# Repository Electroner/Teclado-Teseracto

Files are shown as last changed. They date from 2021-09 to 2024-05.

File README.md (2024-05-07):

# Teclado Personalizado en Español + PCB  

En este repositorio encontraras desde los datasheet de cada parte que he usado hasta los archivos originales del autocad, con todos los archivos descargados deberias ser capaz de poder crear y manufacturar este teclado sin ningun problema.

Este teclado usa un Atmega32u4 como controllador y un decodificador/Demultiplexor CD74HC154 4-a-16, Suficiente para conseguir un tiempo de respuesta igual o superior a los mejores teclados comerciales actuales (1060Hz).Pruebas realizadas con el codigo actual. Ademas se ha decido "prescindir" de un teclado numerico real, y lo que se ha hecho es conectar los numeros del numpad a  los numeros de la parte superior del teclado, por lo que las teclas tanto del numpad como los de la parte superior son los mismas, al igual con el intro y "." (Ver Esquematica).

Para el cuerpo y Plate se ha optado por una fabricacion completa de metacrilato atornillada de extremo a extremo con 28 tornillos que provocaran una sujeccion y una robustez sin igual. El diseño en todo momento de cada parte se ha realizado pensando en su mantenimiento y facilidad de reparacion.

Se ha actualizado a la version N-keyRollOver con unas modificaciones en las librerias de Keyboard.h y Keyboard.cpp

## Imagenes

Teclado Finalizado (No leds):

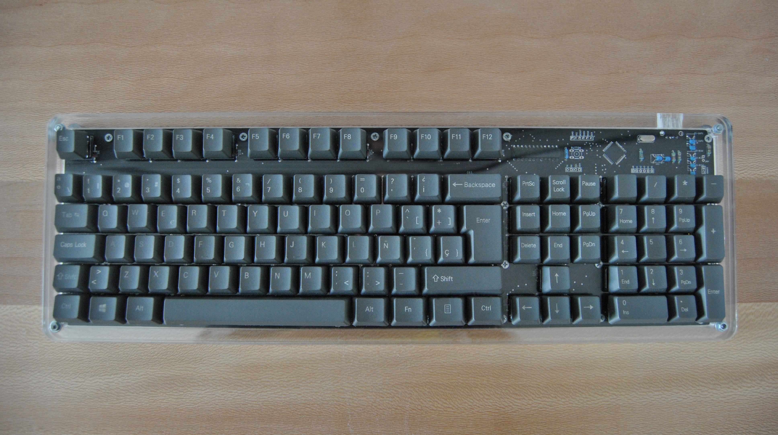
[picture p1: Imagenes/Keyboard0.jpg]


TECLADO

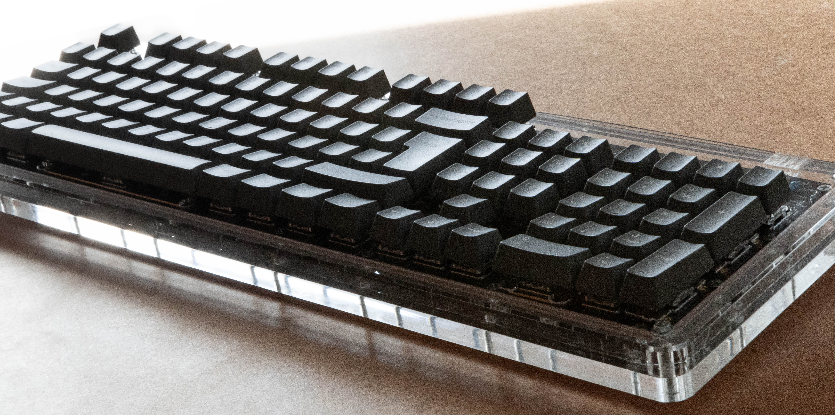
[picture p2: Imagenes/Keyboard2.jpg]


TECLADO

TECLADO

Teclado Finalizado (Leds):

TECLADO

Componentes de la PCB:

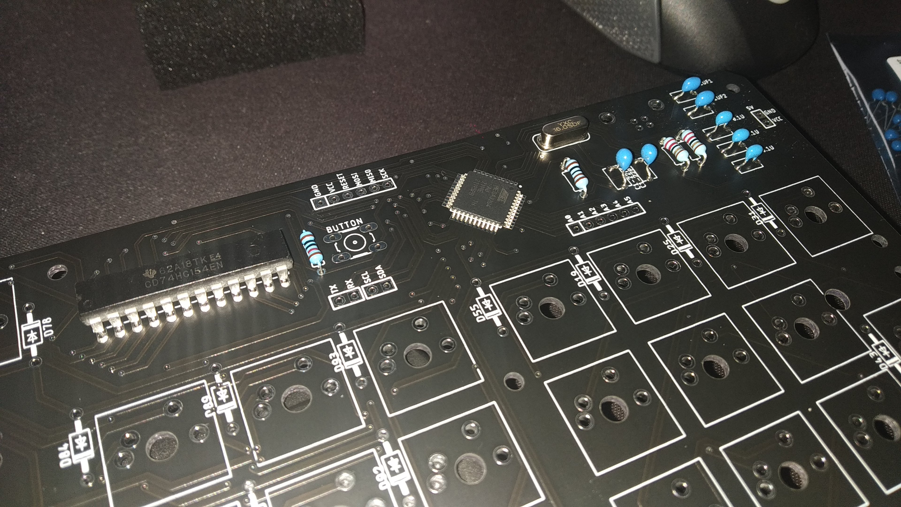
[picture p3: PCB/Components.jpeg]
PCB


Vista Previa de la PCB:

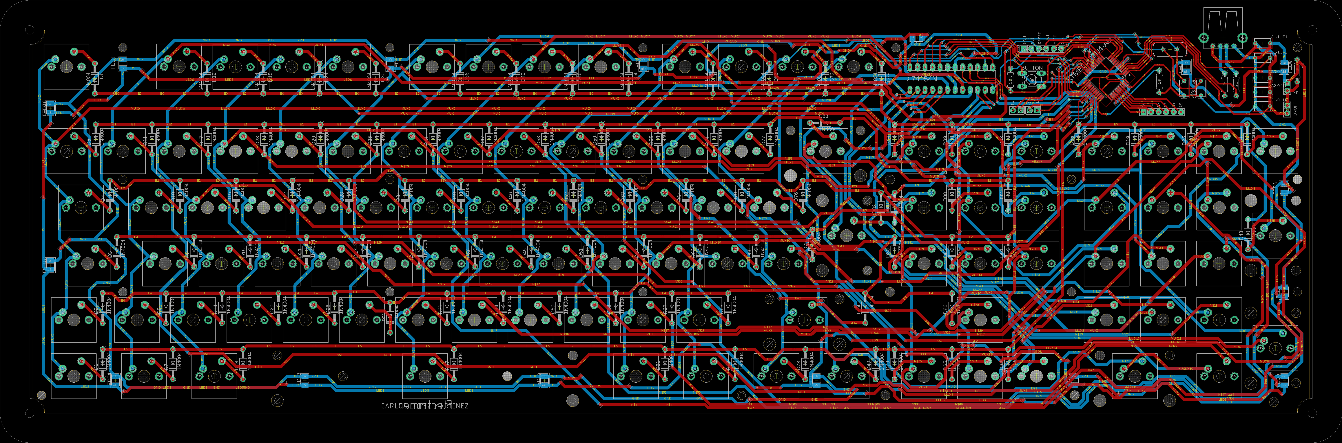
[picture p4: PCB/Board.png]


Schematic:

PLANO

Plano Plancha Superior (Plate):

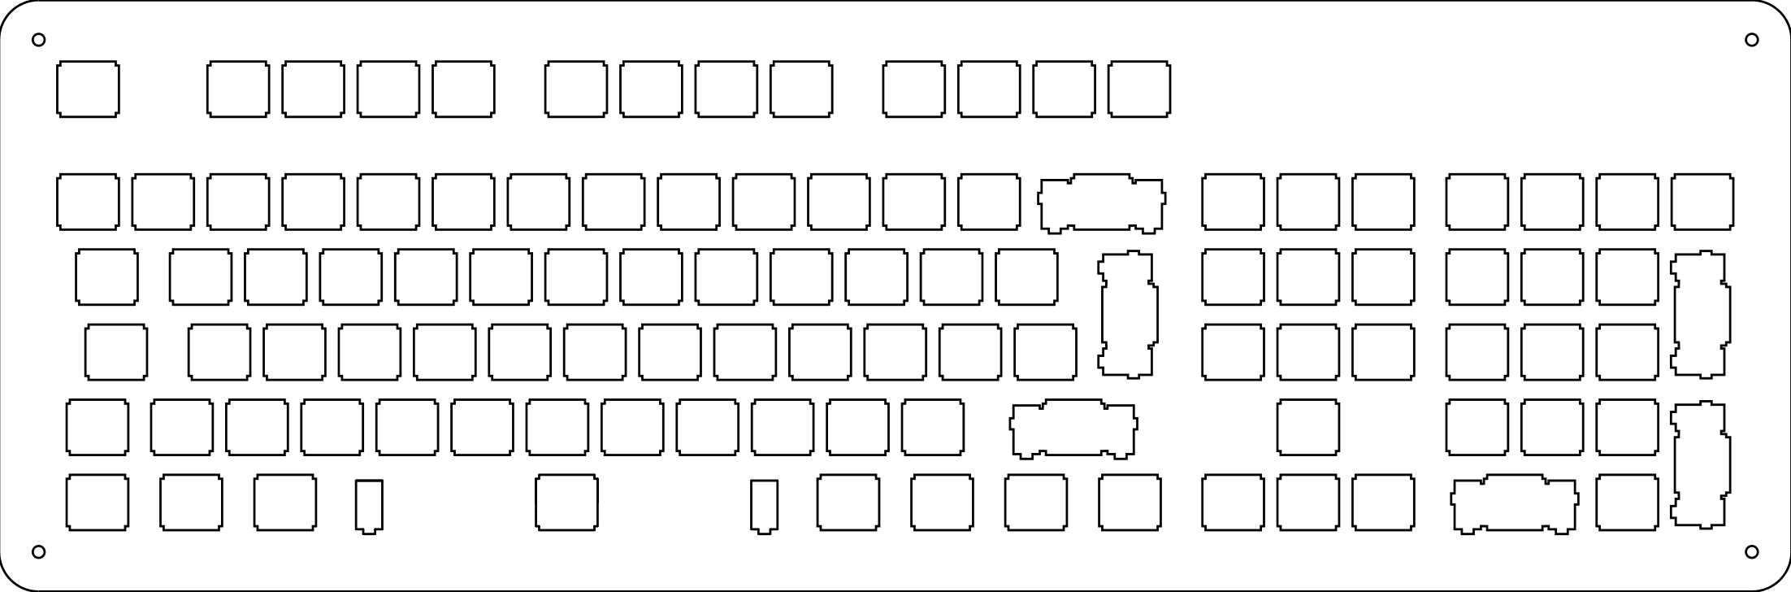
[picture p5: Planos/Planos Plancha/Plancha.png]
PLANO


## Recursos Usados

-   [Alguna Investigacion y aprendizaje](https://github.com/w4ilun/pocket-keyboard)

Y varias paginas para datos concretos como funciones en eagle,ayuda con el bootloader y ejemplos de otros teclados.

-   [Ayuda con el bootloader](https://forum.arduino.cc/t/burning-bootloader-to-custom-board-atmega32u4/890015)
-   [Ayuda con el N-key](https://forum.arduino.cc/t/how-to-program-n-key-rollover-atmega32u4/938418)

## Software Usado

-   [Editor de Layaout Teclado](http://www.keyboard-layout-editor.com/)
-   [Autocad](https://www.autodesk.es/products/autocad/overview?term=1-YEAR&tab=subscription)
-   [FreeCad](https://www.freecadweb.org/)
-   [Eagle](https://www.autodesk.com/products/eagle/free-download)
-   [Componentes Eagle](https://componentsearchengine.com/)
-   [Produccion de la PCB](https://jlcpcb.com/)
-   [Compra de los componentes](https://lcsc.com/)
-   [Corte de metacrilato (Tienda Local)](https://ecoplasticlaser.com/)

## Instalacion y Compilacion

Recomiendo el Arduino 1.8 (Legacy IDE (1.8.X)) en su version portable. 
Para poder compilar la placa y añadir los archivos personalizados vamos a seguir estos pasos:

1. En ./hardware/ meteremos la carpeta CLMKeyboard donde estan los archivos personalizados.
2. Dentro de las librerias (./libraries/Keyboard) vamos a sustituir los archivos keyboard.c y Keyboard.h
3. Dentro de arduino deberia aparacer nuestra Placa como CLM Keyboard.
4. Compilamos y subimos.

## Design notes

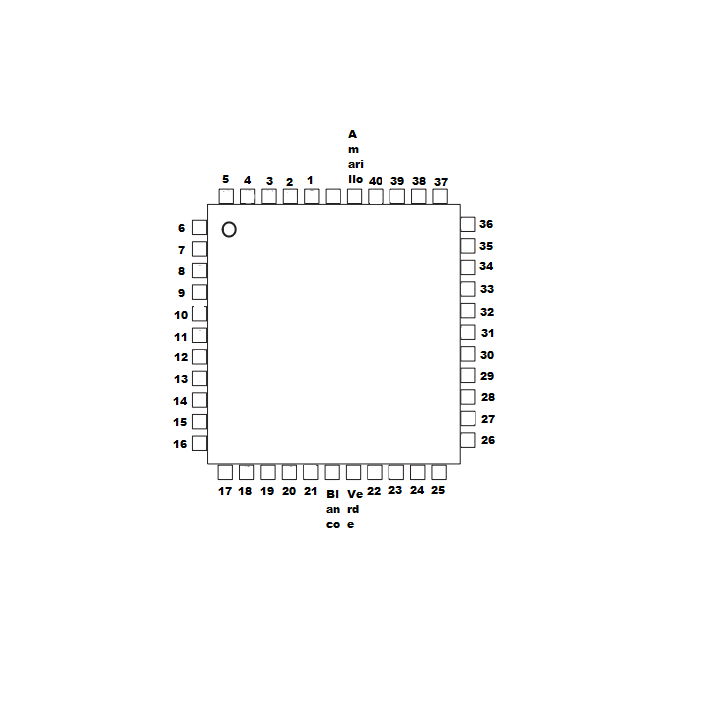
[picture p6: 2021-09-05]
Componentes/Pinout Programador.png

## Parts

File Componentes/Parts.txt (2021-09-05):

https://www.lcsc.com/product-detail/Switching-Diode_ST-Semtech-1N4148_C14516.html
https://www.lcsc.com/product-detail/Multilayer-Ceramic-Capacitors-MLCC-Leaded_Dersonic-CD1H220JC9BECHD000_C263190.html
https://www.lcsc.com/product-detail/Crystals_Yangxing-Tech-X49SD16MSD2SC_C16212.html
https://www.lcsc.com/product-detail/Multilayer-Ceramic-Capacitors-MLCC-Leaded_Dersonic-CD1H105MC9BEF4E000_C263189.html
https://www.lcsc.com/product-detail/Multilayer-Ceramic-Capacitors-MLCC-Leaded_Murata-Electronics-RDER71H104K0K1H03B_C162685.html
https://www.lcsc.com/product-detail/Through-Hole-Resistors_UNI-ROYAL-Uniroyal-Elec-MFR0W4F220JA50_C58611.html
https://www.lcsc.com/product-detail/Through-Hole-Resistors_UNI-ROYAL-Uniroyal-Elec-MFR0W4F1001A50_C57435.html
https://www.lcsc.com/product-detail/ATMEL-AVR_Microchip-Tech-ATMEGA32U4-AU_C44854.html
https://es.aliexpress.com/item/1005002657470319.html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

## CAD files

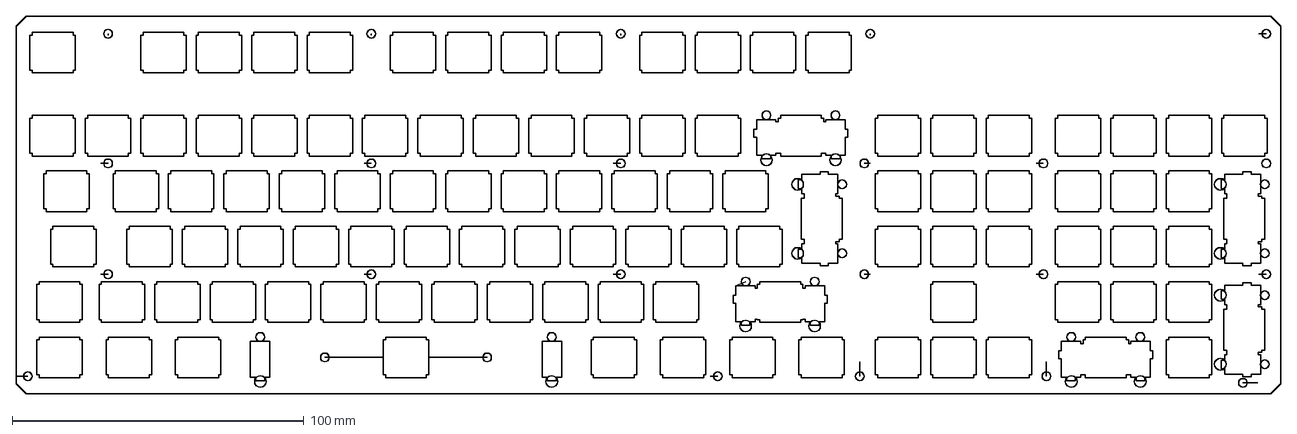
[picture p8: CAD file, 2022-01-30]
Planos/Plano PCB/PCB.dxf
433.5 x 129.5 mm

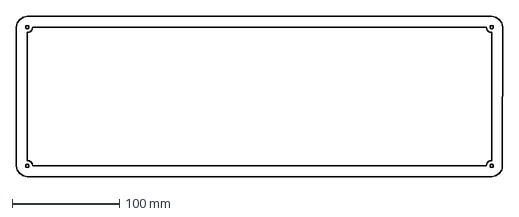
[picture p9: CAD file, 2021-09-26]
Planos/Planos Carcasa/Borde.dxf
453.5 x 149.5 mm

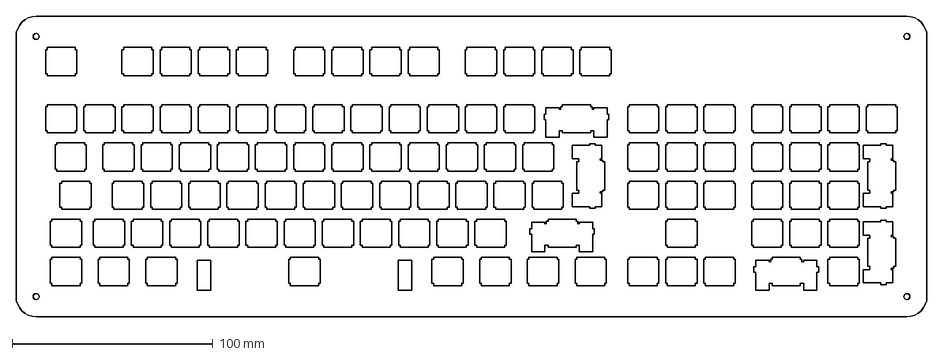
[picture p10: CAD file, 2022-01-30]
Planos/Planos Plancha/Plate.dxf
453.5 x 149.5 mm

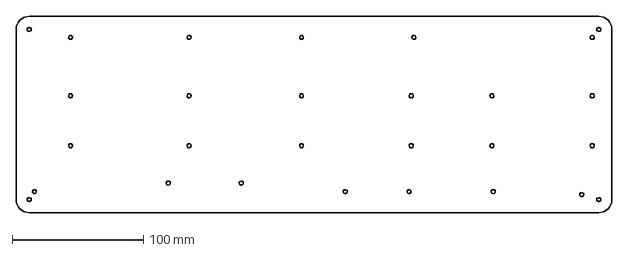
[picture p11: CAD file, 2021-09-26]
Planos/Planos Carcasa/Plancha Inferior.dxf
453.5 x 149.5 mm

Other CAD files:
Planos/Plano PCB/PCB.dwg
Planos/Planos Carcasa/Borde.dwg
Planos/Planos Carcasa/Plancha Inferior.dwg
Planos/Planos Plancha/Plate.dwg

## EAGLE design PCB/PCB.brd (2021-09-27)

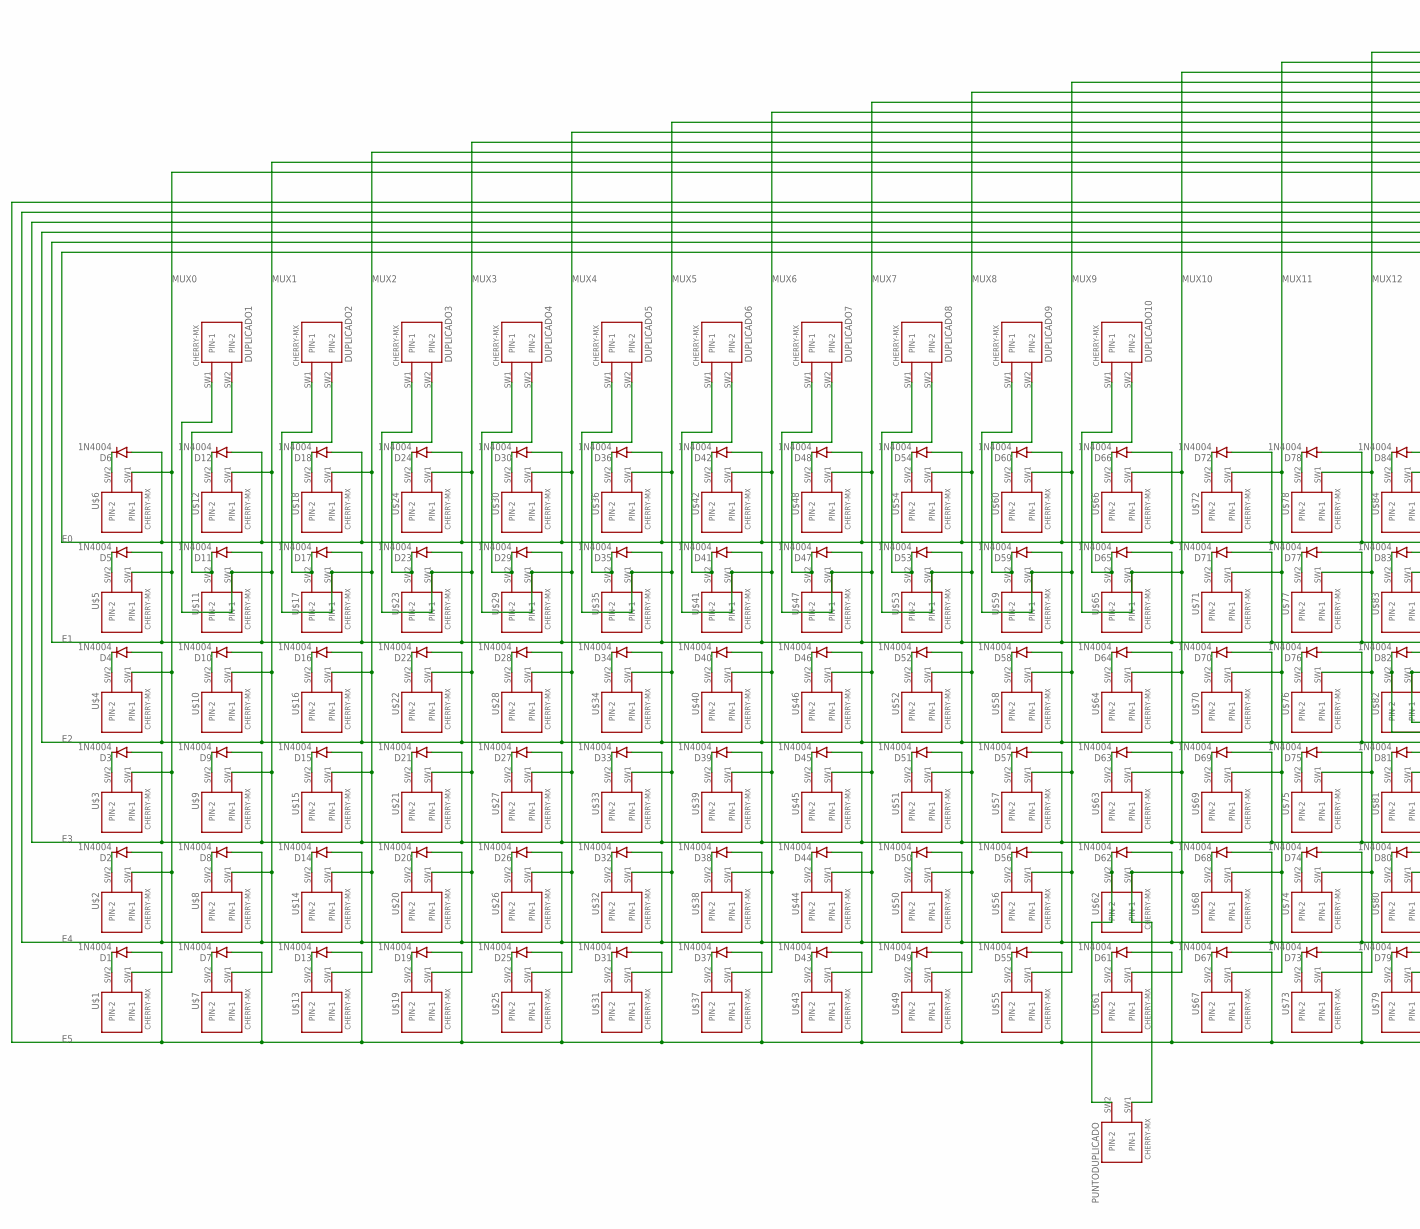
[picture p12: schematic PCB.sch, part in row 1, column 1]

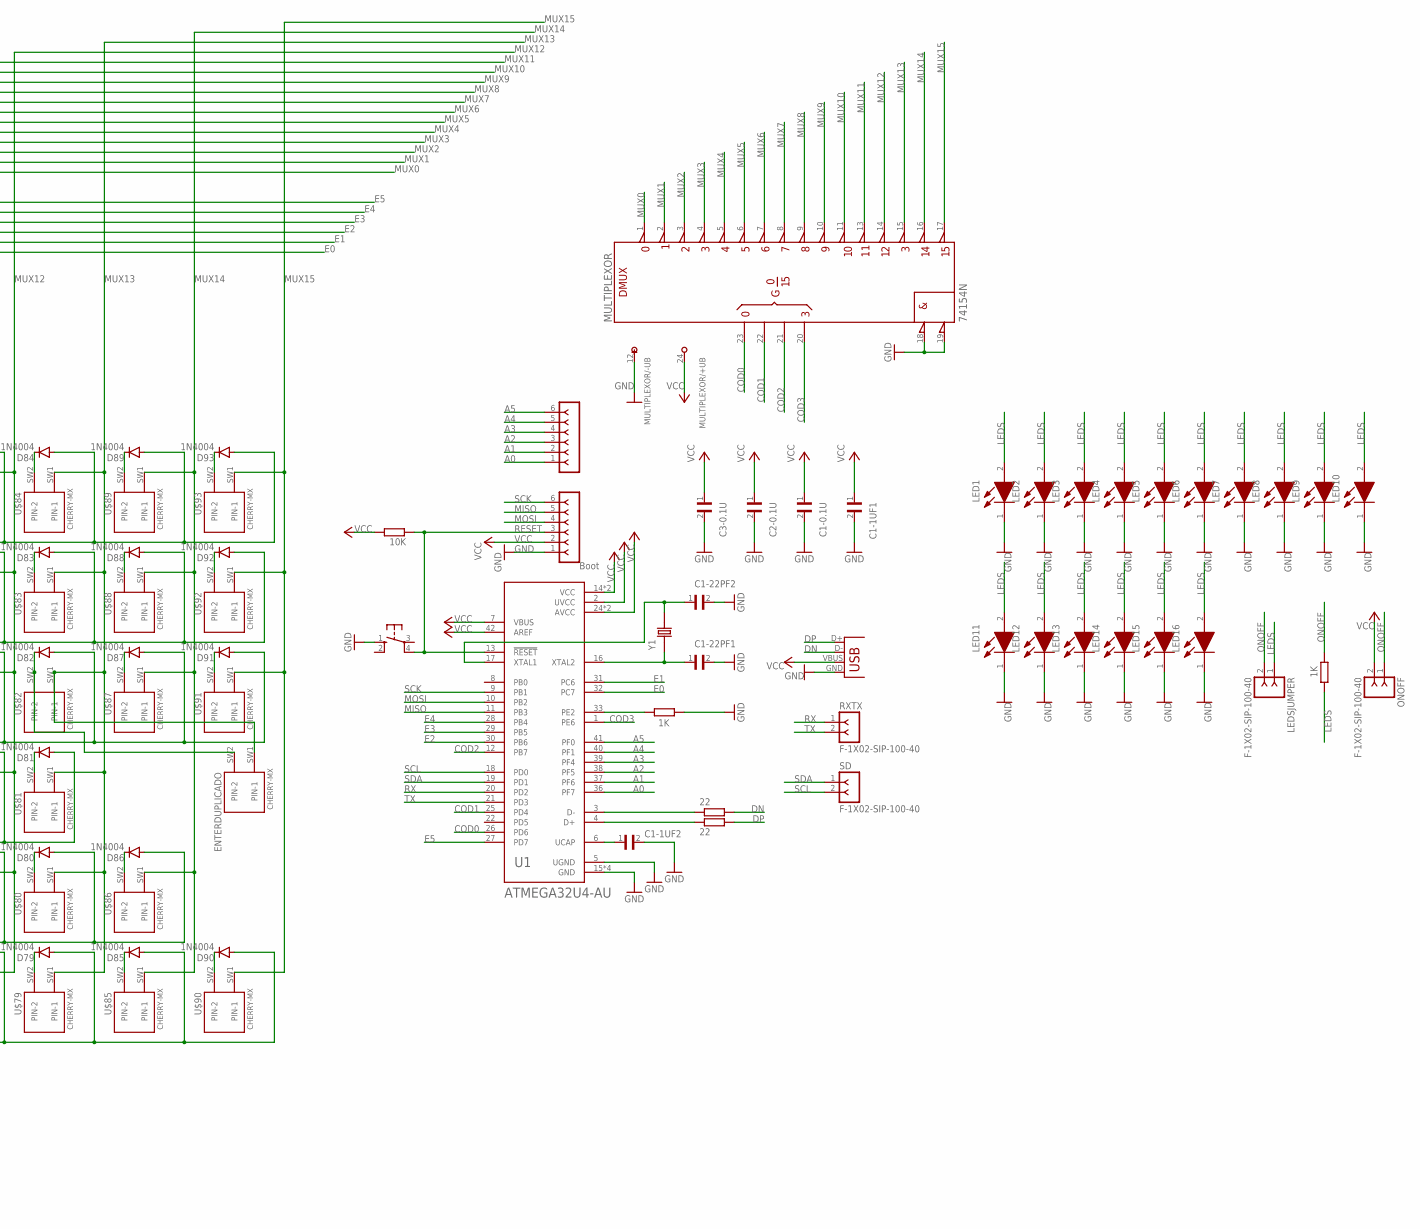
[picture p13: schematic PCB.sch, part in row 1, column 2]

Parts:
ANALOG: Boot; SIP-100-06-32
BUTTON: 10-XX; B3F-10XX
C1-0.1U, C1-1UF1, C1-1UF2, C1-22PF1, C1-22PF2, C2-0.1U, C3-0.1U: RDE5C1H273J2M1H03A; CAP_RDE5C1H273J2M1H03A
D1, D2, D3, D4, D5, D6, D7, D8, D9, D10, D11, D12, D13, D14, D15, D16, D17, D18, D19, D20, D21, D22, D23, D24, D25, D26, D27, D28, D29, D30, D31, D32, D33, D34, D35, D36, D37, D38, D39, D40, D41, D42, D43, D44, D45, D46, D47, D48, D49, D50, D51, D52, D53, D54, D55, D56, D57, D58, D59, D60, D61, D62, D63, D64, D65, D66, D67, D68, D69, D70, D71, D72, D73, D74, D75, D76, D77, D78, D79, D80, D81, D82, D83, D84, D85, D86, D87, D88, D89, D90, D91, D92, D93: 1N4004; DO41-10
DUPLICADO1, DUPLICADO2, DUPLICADO3, DUPLICADO4, DUPLICADO5, DUPLICADO6, DUPLICADO7, DUPLICADO8, DUPLICADO9, DUPLICADO10: CHERRY-MX
ENTERDUPLICADO: CHERRY-MX
J3: Boot; SIP-100-06-32
LED1, LED2, LED3, LED4, LED5, LED6, LED7, LED8, LED9, LED10, LED11, LED12, LED13, LED14, LED15, LED16: ASMM-CA03-AS402; LEDM3528X200N
LEDSJUMPER: F-1X02-SIP-100-40; SIP-100-02-40
MULTIPLEXOR: 74154N; DIL24-3
ONOFF: F-1X02-SIP-100-40; SIP-100-02-40
PUNTODUPLICADO: CHERRY-MX
R1, R2: 22; 0204/7
R3, R4: 1K; 0204/7
R5: 10K; 0204/7
RXTX: F-1X02-SIP-100-40; SIP-100-02-40
SD: F-1X02-SIP-100-40; SIP-100-02-40
U1: ATMEGA32U4-AU; QFP80P1200X1200X120-44N
U$1, U$2, U$3, U$4, U$5, U$6, U$7, U$8, U$9, U$10, U$11, U$12, U$13, U$14, U$15, U$16, U$17, U$18, U$19, U$20, U$21, U$22, U$23, U$24, U$25, U$26, U$27, U$28, U$29, U$30, U$31, U$32, U$33, U$34, U$35, U$36, U$37, U$38, U$39, U$40, U$41, U$42, U$43, U$44, U$45, U$46, U$47, U$48, U$49, U$50, U$51, U$52, U$53, U$54, U$55, U$56, U$57, U$58, U$59, U$60, U$61, U$62, U$63, U$64, U$65, U$66, U$67, U$68, U$69, U$70, U$71, U$72, U$73, U$74, U$75, U$76, U$77, U$78, U$79, U$80, U$81, U$82, U$83, U$84, U$85, U$86, U$87, U$88, U$89, U$90, U$91, U$92, U$93: CHERRY-MX
X2: USB-A-H
Y1: ECS-160-20-4X; XTAL_ECS-160-20-4X

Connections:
A0: ANALOG.1, U1.36 (PF7)
A1: ANALOG.2, U1.37 (PF6)
A2: ANALOG.3, U1.38 (PF5)
A3: ANALOG.4, U1.39 (PF4)
A4: ANALOG.5, U1.40 (PF1)
A5: ANALOG.6, U1.41 (PF0)
COD0: MULTIPLEXOR.23 (A), U1.26 (PD6)
COD1: MULTIPLEXOR.22 (B), U1.25 (PD4)
COD2: MULTIPLEXOR.21 (C), U1.12 (PB7)
COD3: MULTIPLEXOR.20 (D), U1.1 (PE6)
D+: R1.1, U1.4 (D+)
D-: R2.1, U1.3 (D-)
DN: R2.2, X2.D-
DP: R1.2, X2.D+
E0: D6.A, D12.A, D18.A, D24.A, D30.A, D36.A, D42.A, D48.A, D54.A, D60.A, D66.A, D72.A, D78.A, D84.A, D89.A, D93.A, U1.32 (PC7)
E1: D5.A, D11.A, D17.A, D23.A, D29.A, D35.A, D41.A, D47.A, D53.A, D59.A, D65.A, D71.A, D77.A, D83.A, D88.A, D92.A, U1.31 (PC6)
E2: D4.A, D10.A, D16.A, D22.A, D28.A, D34.A, D40.A, D46.A, D52.A, D58.A, D64.A, D70.A, D76.A, D82.A, D87.A, D91.A, U1.30 (PB6)
E3: D3.A, D9.A, D15.A, D21.A, D27.A, D33.A, D39.A, D45.A, D51.A, D57.A, D63.A, D69.A, D75.A, D81.A, U1.29 (PB5)
E4: D2.A, D8.A, D14.A, D20.A, D26.A, D32.A, D38.A, D44.A, D50.A, D56.A, D62.A, D68.A, D74.A, D80.A, D86.A, U1.28 (PB4)
E5: D1.A, D7.A, D13.A, D19.A, D25.A, D31.A, D37.A, D43.A, D49.A, D55.A, D61.A, D67.A, D73.A, D79.A, D85.A, D90.A, U1.27 (PD7)
GND: BUTTON.1 (S), C1-0.1U.2, C1-1UF1.2, C1-1UF2.2, C1-22PF1.2, C1-22PF2.2, C2-0.1U.2, C3-0.1U.2, J3.1, LED1.1 (K), LED2.1 (K), LED3.1 (K), LED4.1 (K), LED5.1 (K), LED6.1 (K), LED7.1 (K), LED8.1 (K), LED9.1 (K), LED10.1 (K), LED11.1 (K), LED12.1 (K), LED13.1 (K), LED14.1 (K), LED15.1 (K), LED16.1 (K), MULTIPLEXOR.12 (-UB), MULTIPLEXOR.18 (!G1), MULTIPLEXOR.19 (!G2), R4.1, U1.5 (UGND), U1.15 (GND), U1.23 (GND), U1.35 (GND), U1.43 (GND), X2.GND
LEDS: LED1.2 (A), LED2.2 (A), LED3.2 (A), LED4.2 (A), LED5.2 (A), LED6.2 (A), LED7.2 (A), LED8.2 (A), LED9.2 (A), LED10.2 (A), LED11.2 (A), LED12.2 (A), LED13.2 (A), LED14.2 (A), LED15.2 (A), LED16.2 (A), LEDSJUMPER.1, R3.1
MISO: J3.5, U1.11 (PB3)
MOSI: J3.4, U1.10 (PB2)
MUX0: MULTIPLEXOR.1 (0), U$1.SW1 (PIN-1), U$2.SW1 (PIN-1), U$3.SW1 (PIN-1), U$4.SW1 (PIN-1), U$5.SW1 (PIN-1), U$6.SW1 (PIN-1)
MUX1: DUPLICADO1.SW1 (PIN-1), MULTIPLEXOR.2 (1), U$7.SW1 (PIN-1), U$8.SW1 (PIN-1), U$9.SW1 (PIN-1), U$10.SW1 (PIN-1), U$11.SW1 (PIN-1), U$12.SW1 (PIN-1)
MUX2: DUPLICADO2.SW1 (PIN-1), MULTIPLEXOR.3 (2), U$13.SW1 (PIN-1), U$14.SW1 (PIN-1), U$15.SW1 (PIN-1), U$16.SW1 (PIN-1), U$17.SW1 (PIN-1), U$18.SW1 (PIN-1)
MUX3: DUPLICADO3.SW1 (PIN-1), MULTIPLEXOR.4 (3), U$19.SW1 (PIN-1), U$20.SW1 (PIN-1), U$21.SW1 (PIN-1), U$22.SW1 (PIN-1), U$23.SW1 (PIN-1), U$24.SW1 (PIN-1)
MUX4: DUPLICADO4.SW1 (PIN-1), MULTIPLEXOR.5 (4), U$25.SW1 (PIN-1), U$26.SW1 (PIN-1), U$27.SW1 (PIN-1), U$28.SW1 (PIN-1), U$29.SW1 (PIN-1), U$30.SW1 (PIN-1)
MUX5: DUPLICADO5.SW1 (PIN-1), MULTIPLEXOR.6 (5), U$31.SW1 (PIN-1), U$32.SW1 (PIN-1), U$33.SW1 (PIN-1), U$34.SW1 (PIN-1), U$35.SW1 (PIN-1), U$36.SW1 (PIN-1)
MUX6: DUPLICADO6.SW1 (PIN-1), MULTIPLEXOR.7 (6), U$37.SW1 (PIN-1), U$38.SW1 (PIN-1), U$39.SW1 (PIN-1), U$40.SW1 (PIN-1), U$41.SW1 (PIN-1), U$42.SW1 (PIN-1)
MUX7: DUPLICADO7.SW1 (PIN-1), MULTIPLEXOR.8 (7), U$43.SW1 (PIN-1), U$44.SW1 (PIN-1), U$45.SW1 (PIN-1), U$46.SW1 (PIN-1), U$47.SW1 (PIN-1), U$48.SW1 (PIN-1)
MUX8: DUPLICADO8.SW1 (PIN-1), MULTIPLEXOR.9 (8), U$49.SW1 (PIN-1), U$50.SW1 (PIN-1), U$51.SW1 (PIN-1), U$52.SW1 (PIN-1), U$53.SW1 (PIN-1), U$54.SW1 (PIN-1)
MUX9: DUPLICADO9.SW1 (PIN-1), MULTIPLEXOR.10 (9), U$55.SW1 (PIN-1), U$56.SW1 (PIN-1), U$57.SW1 (PIN-1), U$58.SW1 (PIN-1), U$59.SW1 (PIN-1), U$60.SW1 (PIN-1)
MUX10: DUPLICADO10.SW1 (PIN-1), MULTIPLEXOR.11 (10), PUNTODUPLICADO.SW1 (PIN-1), U$61.SW1 (PIN-1), U$62.SW1 (PIN-1), U$63.SW1 (PIN-1), U$64.SW1 (PIN-1), U$65.SW1 (PIN-1), U$66.SW1 (PIN-1)
MUX11: MULTIPLEXOR.13 (11), U$67.SW1 (PIN-1), U$68.SW1 (PIN-1), U$69.SW1 (PIN-1), U$70.SW1 (PIN-1), U$71.SW1 (PIN-1), U$72.SW1 (PIN-1)
MUX12: MULTIPLEXOR.14 (12), U$73.SW1 (PIN-1), U$74.SW1 (PIN-1), U$75.SW1 (PIN-1), U$76.SW1 (PIN-1), U$77.SW1 (PIN-1), U$78.SW1 (PIN-1)
MUX13: ENTERDUPLICADO.SW1 (PIN-1), MULTIPLEXOR.15 (13), U$79.SW1 (PIN-1), U$80.SW1 (PIN-1), U$81.SW1 (PIN-1), U$82.SW1 (PIN-1), U$83.SW1 (PIN-1), U$84.SW1 (PIN-1)
MUX14: MULTIPLEXOR.16 (14), U$85.SW1 (PIN-1), U$86.SW1 (PIN-1), U$87.SW1 (PIN-1), U$88.SW1 (PIN-1), U$89.SW1 (PIN-1)
MUX15: MULTIPLEXOR.17 (15), U$90.SW1 (PIN-1), U$91.SW1 (PIN-1), U$92.SW1 (PIN-1), U$93.SW1 (PIN-1)
unnamed: D4.C, U$4.SW2 (PIN-2)
unnamed: D10.C, U$10.SW2 (PIN-2)
unnamed: D16.C, U$16.SW2 (PIN-2)
unnamed: D22.C, U$22.SW2 (PIN-2)
unnamed: D5.C, U$5.SW2 (PIN-2)
unnamed: D6.C, U$6.SW2 (PIN-2)
unnamed: D28.C, U$28.SW2 (PIN-2)
unnamed: D34.C, U$34.SW2 (PIN-2)
unnamed: D40.C, U$40.SW2 (PIN-2)
unnamed: D46.C, U$46.SW2 (PIN-2)
unnamed: D11.C, DUPLICADO1.SW2 (PIN-2), U$11.SW2 (PIN-2)
unnamed: D12.C, U$12.SW2 (PIN-2)
unnamed: D52.C, U$52.SW2 (PIN-2)
unnamed: D58.C, U$58.SW2 (PIN-2)
unnamed: D64.C, U$64.SW2 (PIN-2)
unnamed: D70.C, U$70.SW2 (PIN-2)
unnamed: D17.C, DUPLICADO2.SW2 (PIN-2), U$17.SW2 (PIN-2)
unnamed: D18.C, U$18.SW2 (PIN-2)
unnamed: D76.C, U$76.SW2 (PIN-2)
unnamed: D87.C, U$87.SW2 (PIN-2)
unnamed: D91.C, U$91.SW2 (PIN-2)
unnamed: D81.C, U$81.SW2 (PIN-2)
unnamed: D23.C, DUPLICADO3.SW2 (PIN-2), U$23.SW2 (PIN-2)
unnamed: D24.C, U$24.SW2 (PIN-2)
unnamed: D75.C, U$75.SW2 (PIN-2)
unnamed: D69.C, U$69.SW2 (PIN-2)
unnamed: D63.C, U$63.SW2 (PIN-2)
unnamed: D57.C, U$57.SW2 (PIN-2)
unnamed: D29.C, DUPLICADO4.SW2 (PIN-2), U$29.SW2 (PIN-2)
unnamed: D30.C, U$30.SW2 (PIN-2)
unnamed: D51.C, U$51.SW2 (PIN-2)
unnamed: D45.C, U$45.SW2 (PIN-2)
unnamed: D39.C, U$39.SW2 (PIN-2)
unnamed: D33.C, U$33.SW2 (PIN-2)
unnamed: D35.C, DUPLICADO5.SW2 (PIN-2), U$35.SW2 (PIN-2)
unnamed: D36.C, U$36.SW2 (PIN-2)
unnamed: D27.C, U$27.SW2 (PIN-2)
unnamed: D21.C, U$21.SW2 (PIN-2)
unnamed: D15.C, U$15.SW2 (PIN-2)
unnamed: D9.C, U$9.SW2 (PIN-2)
unnamed: D41.C, DUPLICADO6.SW2 (PIN-2), U$41.SW2 (PIN-2)
unnamed: D42.C, U$42.SW2 (PIN-2)
unnamed: D3.C, U$3.SW2 (PIN-2)
unnamed: D2.C, U$2.SW2 (PIN-2)
unnamed: D8.C, U$8.SW2 (PIN-2)
unnamed: D14.C, U$14.SW2 (PIN-2)
unnamed: D47.C, DUPLICADO7.SW2 (PIN-2), U$47.SW2 (PIN-2)
unnamed: D48.C, U$48.SW2 (PIN-2)
unnamed: D20.C, U$20.SW2 (PIN-2)
unnamed: D26.C, U$26.SW2 (PIN-2)
unnamed: D32.C, U$32.SW2 (PIN-2)
unnamed: D38.C, U$38.SW2 (PIN-2)
unnamed: D53.C, DUPLICADO8.SW2 (PIN-2), U$53.SW2 (PIN-2)
unnamed: D54.C, U$54.SW2 (PIN-2)
unnamed: D44.C, U$44.SW2 (PIN-2)
unnamed: D50.C, U$50.SW2 (PIN-2)
unnamed: D56.C, U$56.SW2 (PIN-2)
unnamed: D68.C, U$68.SW2 (PIN-2)
unnamed: D59.C, DUPLICADO9.SW2 (PIN-2), U$59.SW2 (PIN-2)
unnamed: D60.C, U$60.SW2 (PIN-2)
unnamed: D74.C, U$74.SW2 (PIN-2)
unnamed: D62.C, PUNTODUPLICADO.SW2 (PIN-2), U$62.SW2 (PIN-2)
unnamed: D80.C, U$80.SW2 (PIN-2)
unnamed: D86.C, U$86.SW2 (PIN-2)
unnamed: D65.C, DUPLICADO10.SW2 (PIN-2), U$65.SW2 (PIN-2)
unnamed: D66.C, U$66.SW2 (PIN-2)
unnamed: D90.C, U$90.SW2 (PIN-2)
unnamed: D85.C, U$85.SW2 (PIN-2)
unnamed: D79.C, U$79.SW2 (PIN-2)
unnamed: D73.C, U$73.SW2 (PIN-2)
unnamed: D71.C, U$71.SW2 (PIN-2)
unnamed: D72.C, U$72.SW2 (PIN-2)
unnamed: D67.C, U$67.SW2 (PIN-2)
unnamed: D61.C, U$61.SW2 (PIN-2)
unnamed: D55.C, U$55.SW2 (PIN-2)
unnamed: D49.C, U$49.SW2 (PIN-2)
unnamed: D77.C, U$77.SW2 (PIN-2)
unnamed: D78.C, U$78.SW2 (PIN-2)
unnamed: D43.C, U$43.SW2 (PIN-2)
unnamed: D37.C, U$37.SW2 (PIN-2)
unnamed: D31.C, U$31.SW2 (PIN-2)
unnamed: D82.C, ENTERDUPLICADO.SW2 (PIN-2), U$82.SW2 (PIN-2)
unnamed: D83.C, U$83.SW2 (PIN-2)
unnamed: D84.C, U$84.SW2 (PIN-2)
unnamed: D25.C, U$25.SW2 (PIN-2)
unnamed: D19.C, U$19.SW2 (PIN-2)
unnamed: D13.C, U$13.SW2 (PIN-2)
unnamed: D88.C, U$88.SW2 (PIN-2)
unnamed: D89.C, U$89.SW2 (PIN-2)
unnamed: D7.C, U$7.SW2 (PIN-2)
unnamed: D1.C, U$1.SW2 (PIN-2)
unnamed: D92.C, U$92.SW2 (PIN-2)
unnamed: D93.C, U$93.SW2 (PIN-2)
ONOFF: LEDSJUMPER.2, ONOFF.1, R3.2
PE2: R4.2, U1.33 (PE2)
RESET: BUTTON.4 (P1), J3.3, R5.2, U1.13 (!RESET)
RX: RXTX.1, U1.20 (PD2)
SCK: J3.6, U1.9 (PB1)
SCL: SD.2, U1.18 (PD0)
SDA: SD.1, U1.19 (PD1)
TX: RXTX.2, U1.21 (PD3)
UCAP: C1-1UF2.1, U1.6 (UCAP)
VCC: C1-0.1U.1, C1-1UF1.1, C2-0.1U.1, C3-0.1U.1, J3.2, MULTIPLEXOR.24 (+UB), ONOFF.2, R5.1, U1.2 (UVCC), U1.7 (VBUS), U1.14 (VCC), U1.24 (AVCC), U1.34 (VCC), U1.42 (AREF), U1.44 (AVCC), X2.VBUS
XTAL1: C1-22PF2.1, U1.17 (XTAL1), Y1.2
XTAL2: C1-22PF1.1, U1.16 (XTAL2), Y1.1

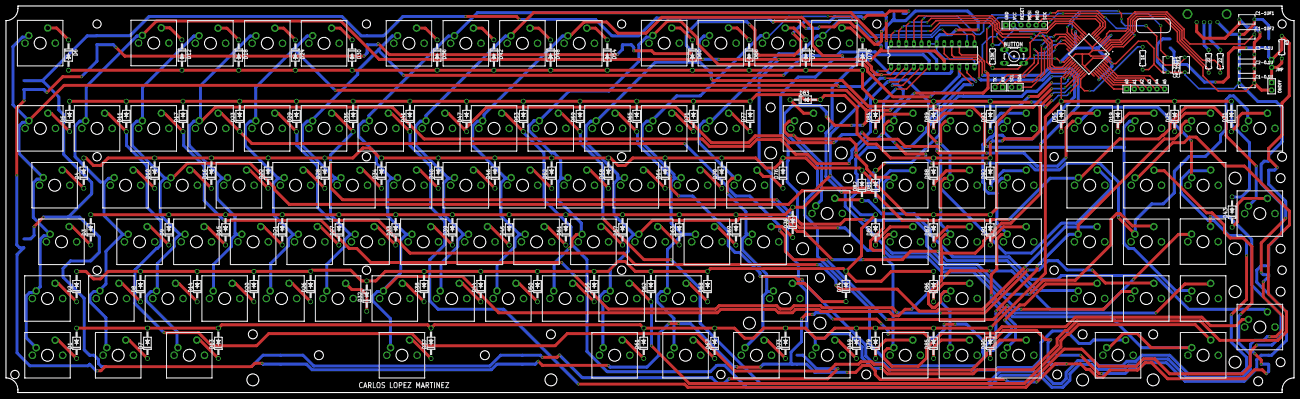
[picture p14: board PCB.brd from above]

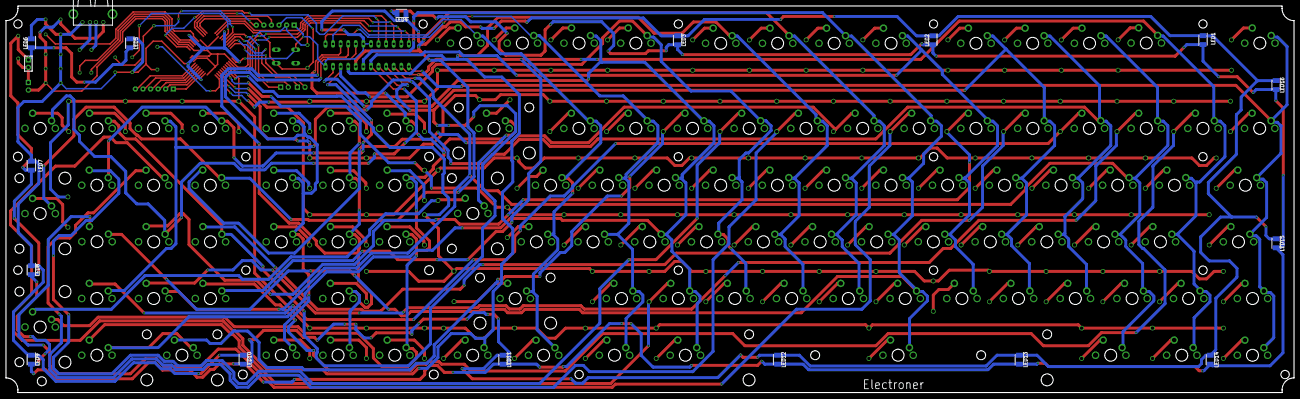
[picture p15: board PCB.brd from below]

Board: 2 copper layers, 431.5 x 129.5 mm, 237 parts (18 on the bottom side), 145 nets.

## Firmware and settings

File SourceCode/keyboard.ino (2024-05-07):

#include <Keyboard.h>

#define KEY_NONE 0
#define KEY_BACKSPACE 8
#define KEY_TAB 9
#define KEY_ENTER 10
#define KEY_ESPACIO 32
#define KEY_ACENTO 39       // ´ Al lado de la Ñ
#define KEY_COMA 44         // , Al lado de la M
#define KEY_APOSTROFE 45    // ' Al lado del Backspace
#define KEY_PUNTO 46        // . Al lado del SHIFT derecho
#define KEY_MENOS 47        // - Al lado del Shift derecho
#define KEY_CERO 48
#define KEY_UNO 49
#define KEY_DOS 50
#define KEY_TRES 51
#define KEY_CUATRO 52
#define KEY_CINCO 53
#define KEY_SEIS 54
#define KEY_SIETE 55
#define KEY_OCHO 56
#define KEY_NUEVE 57
#define KEY_ENIE 59
#define KEY_EXCLAMACION 61 // ¡ Al lado del Backspace
#define KEY_ACENTOAGUDO 91  // ` Al lado de la P
#define KEY_CEDILLA 92
#define KEY_SIGNOMAS 93
#define KEY_ANGULO 96
#define KEY_A 97
#define KEY_B 98
#define KEY_C 99
#define KEY_D 100
#define KEY_E 101
#define KEY_F 102
#define KEY_G 103
#define KEY_H 104
#define KEY_I 105
#define KEY_J 106
#define KEY_K 107
#define KEY_L 108
#define KEY_M 109
#define KEY_N 110
#define KEY_O 111
#define KEY_P 112
#define KEY_Q 113
#define KEY_R 114
#define KEY_S 115
#define KEY_T 116
#define KEY_U 117
#define KEY_V 118
#define KEY_W 119
#define KEY_X 120
#define KEY_Y 121
#define KEY_Z 122
#define KEY_LSHIFT 129
#define KEY_LCONTROL 128
#define KEY_LALT 130
#define KEY_WINDOWS 131
#define KEY_RCONTROL 132
#define KEY_RSHIFT 133
#define KEY_ALTGR 134
#define KEY_ESC 177
#define KEY_CAPSLOCK 193
#define KEY_F1 194
#define KEY_F2 195
#define KEY_F3 196
#define KEY_F4 197
#define KEY_F5 198
#define KEY_F6 199
#define KEY_F7 200
#define KEY_F8 201
#define KEY_F9 202
#define KEY_F10 203
#define KEY_F11 204
#define KEY_F12 205
#define KEY_PRINTSCREEN 206
#define KEY_BLOQ 207
#define KEY_PAUSE 208
#define KEY_INS 209
#define KEY_HOME 210
#define KEY_PAGEUP 211
#define KEY_DEL 212
#define KEY_END 213
#define KEY_PAGEDOWN 214
#define KEY_FLECHADERECHA 215
#define KEY_FLECHAIZQUIERDA 216
#define KEY_FLECHAABAJO 217
#define KEY_FLECHAARRIBA 218
#define KEY_NUMLOCK 219
#define KEY_DIVISIONPAD 220
#define KEY_PORPAD 221
#define KEY_MENOSPAD 222
#define KEY_SUMAPAD 223
#define KEY_ENTERPAD 224
#define KEY_UNOPAD 225
#define KEY_DOSPAD 226
#define KEY_TRESPAD 227
#define KEY_CUATROPAD 228
#define KEY_CINCOPAD 229
#define KEY_SEISPAD 230
#define KEY_SIETEPAD 231
#define KEY_OCHOPAD 232
#define KEY_NUEVEPAD 233
#define KEY_CEROPAD 234
#define KEY_PUNTOPAD 235
#define KEY_MENOSMAYOR 236
#define KEY_CONTEXTMENU 237

const unsigned int numsCantidad = 16;   // 16 Numeros del demultiplexor
const unsigned int numsAncho = 4;       // 4 al anchura del numero en binario

const unsigned int AnchuraTeclado = 16; //Tamanio del teclado a lo largo
const unsigned int AlturaTeclado = 6;   //Tamanio del teclado a lo ancho

const unsigned int cod0 = 7; //Asignacino del pin de salida X0 (PD6)
const unsigned int cod1 = 11;  //Asignacino del pin de salida X1 (PD4)
const unsigned int cod2 = 4; //Asignacino del pin de salida X2 (PB7)
const unsigned int cod3 = 12;  //Asignacino del pin de salida X3 (PE6)

const unsigned int E0 = 13; //Asignacino del pin de Entrada E0 (PC7)
const unsigned int E1 = 5;  //Asignacino del pin de Entrada E1 (PC6)
const unsigned int E2 = 10; //Asignacino del pin de Entrada E2 (PB6)
const unsigned int E3 = 9;  //Asignacino del pin de Entrada E3 (PB5)
const unsigned int E4 = 8;  //Asignacino del pin de Entrada E4 (PB4)
const unsigned int E5 = 6;  //Asignacino del pin de Entrada E5 (PD7)

const unsigned int ESwitch[AlturaTeclado] = {E0, E1, E2, E3, E4, E5}; // Array de lectura de Fila

const bool nums0_15[numsCantidad][numsAncho] = {{0, 0, 0, 0},
                                                {1, 0, 0, 0},
                                                {0, 1, 0, 0},
                                                {1, 1, 0, 0},
                                                {0, 0, 1, 0},
                                                {1, 0, 1, 0},
                                                {0, 1, 1, 0},
                                                {1, 1, 1, 0},
                                                {0, 0, 0, 1},
                                                {1, 0, 0, 1},
                                                {0, 1, 0, 1},
                                                {1, 1, 0, 1},
                                                {0, 0, 1, 1},
                                                {1, 0, 1, 1},
                                                {0, 1, 1, 1},
                                                {1, 1, 1, 1}};

const unsigned char TeclasTeclado[AlturaTeclado][AnchuraTeclado] = {{KEY_ESC,KEY_F1,KEY_F2,KEY_F3,KEY_F4,KEY_F5,KEY_F6,KEY_F7,KEY_F8,KEY_F9,KEY_F10,KEY_F11,KEY_F12,KEY_PRINTSCREEN,KEY_BLOQ,KEY_PAUSE},
                                                                    {KEY_ANGULO,KEY_UNO,KEY_DOS,KEY_TRES,KEY_CUATRO,KEY_CINCO,KEY_SEIS,KEY_SIETE,KEY_OCHO,KEY_NUEVE,KEY_CERO,KEY_APOSTROFE,KEY_EXCLAMACION,KEY_BACKSPACE,KEY_HOME,KEY_PAGEUP},
                                                                    {KEY_TAB,KEY_Q,KEY_W,KEY_E,KEY_R,KEY_T,KEY_Y,KEY_U,KEY_I,KEY_O,KEY_P,KEY_ACENTOAGUDO,KEY_SIGNOMAS,KEY_ENTER,KEY_END,KEY_PAGEDOWN},
                                                                    {KEY_CAPSLOCK,KEY_A,KEY_S,KEY_D,KEY_F,KEY_G,KEY_H,KEY_J,KEY_K,KEY_L,KEY_ENIE,KEY_ACENTO,KEY_CEDILLA,KEY_INS,KEY_NONE,KEY_NONE},
                                                                    {KEY_LSHIFT,KEY_MENOSMAYOR,KEY_Z,KEY_X,KEY_C,KEY_V,KEY_B,KEY_N,KEY_M,KEY_COMA,KEY_PUNTO,KEY_MENOS,KEY_RSHIFT,KEY_DEL,KEY_FLECHAARRIBA,KEY_NONE},
                                                                    {KEY_LCONTROL,KEY_WINDOWS,KEY_LALT,KEY_DIVISIONPAD,KEY_PORPAD,KEY_MENOSPAD,KEY_ESPACIO,KEY_SUMAPAD,KEY_RCONTROL,KEY_NUMLOCK,KEY_ALTGR,KEY_NONE,KEY_CONTEXTMENU,KEY_FLECHAIZQUIERDA,KEY_FLECHAABAJO,KEY_FLECHADERECHA}};

const unsigned long TiempoDebounce = 5;                             //Tiempo Debounce en milisegundos
bool SwitchEstado[AlturaTeclado][AnchuraTeclado] = {false};         //Estado de la lectura de la fila
bool SwitchEstadoAntiguo[AlturaTeclado][AnchuraTeclado] = {false};  //Estado Anterior de la Tecla
unsigned long Debounce[AlturaTeclado][AnchuraTeclado] = {0};        //Tiempo de Bounce de la fila

void setup()
{
    pinMode(cod0, OUTPUT);
    pinMode(cod1, OUTPUT);
    pinMode(cod2, OUTPUT);
    pinMode(cod3, OUTPUT);

    pinMode(E0, INPUT_PULLUP);
    pinMode(E1, INPUT_PULLUP);
    pinMode(E2, INPUT_PULLUP);
    pinMode(E3, INPUT_PULLUP);
    pinMode(E4, INPUT_PULLUP);
    pinMode(E5, INPUT_PULLUP);
}

void loop()
{
    bool SwicthEstadoRapido;
    for (int i = 0; i < AnchuraTeclado; i++)
    {
        digitalWrite(cod0, nums0_15[i][3]);
        digitalWrite(cod1, nums0_15[i][2]);
        digitalWrite(cod2, nums0_15[i][1]);
        digitalWrite(cod3, nums0_15[i][0]);
        for (int k = 0; k < AlturaTeclado; k++)
        {
            SwicthEstadoRapido = !(digitalRead(ESwitch[k]));
            if (SwicthEstadoRapido && !SwitchEstadoAntiguo[k][i] && (millis() - Debounce[k][i]) > TiempoDebounce)
            {
                Debounce[k][i] = millis();
                SwitchEstadoAntiguo[k][i] = SwicthEstadoRapido;
                Keyboard.press(TeclasTeclado[k][i]);
            }
            else if (!SwicthEstadoRapido && SwitchEstadoAntiguo[k][i] && (millis() - Debounce[k][i]) > TiempoDebounce)
            {
                Debounce[k][i] = millis();
                SwitchEstadoAntiguo[k][i] = SwicthEstadoRapido;
                Keyboard.release(TeclasTeclado[k][i]);

            }
            SwitchEstado[k][i] = SwicthEstadoRapido;
        }
    }
}

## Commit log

2022-01-30 Fixed Stabilizers Size for plate and Updates .dxf of all dwg
    [Plate.dwg, Plate.dxf]
2022-01-30 Finished Revision 2022
    [PCB.dxf]
2023-08-03 Update keyboard.ino
    Fixed Nums order
    [keyboard.ino]
2024-05-07 Update keyboard.ino
    Fixed pin order
    [keyboard.ino]

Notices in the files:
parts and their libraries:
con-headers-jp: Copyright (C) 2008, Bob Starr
